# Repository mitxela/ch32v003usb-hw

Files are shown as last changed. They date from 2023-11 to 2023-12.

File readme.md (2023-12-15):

# CH32V003 USB dev board

This is a simple and tiny USB dev board for the CH32V003 using CNLohr's ch32v003fun and rv003usb.

photo of dev board

2 layer board, 0.8mm thickness.

The 1.5K resistor can be connected either to D5 or to VDD (not both). The series resistors on the underside are optional, cut the traces under them if you want to fit them.

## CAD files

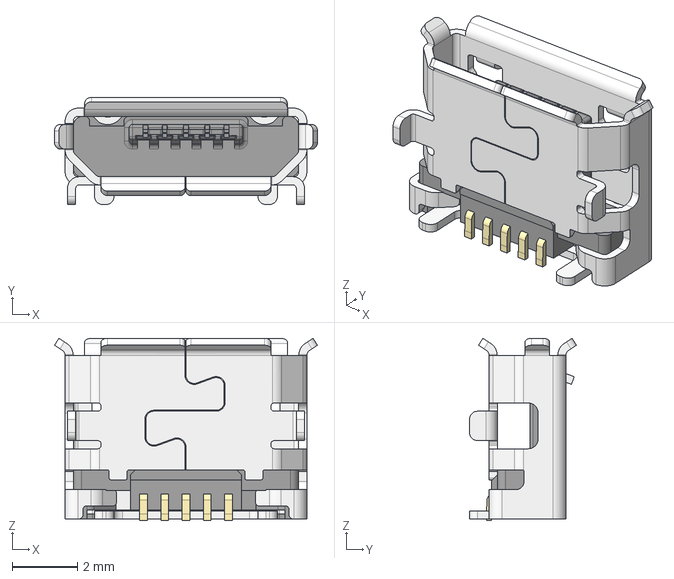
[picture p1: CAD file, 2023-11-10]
10118194-colour.stp
8.05 x 3.27 x 5.58 mm

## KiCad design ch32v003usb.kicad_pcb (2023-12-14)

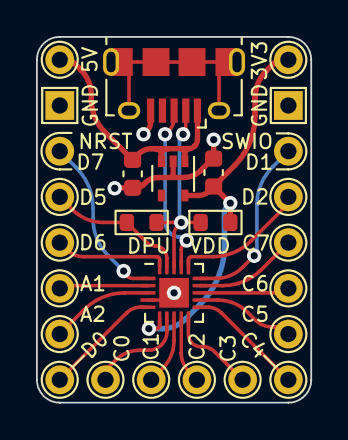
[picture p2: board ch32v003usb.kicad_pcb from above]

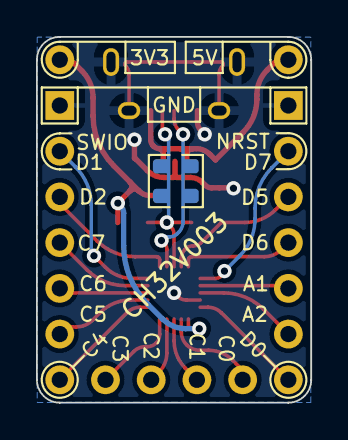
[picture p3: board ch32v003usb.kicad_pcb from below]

Board: 2 copper layers, 15.2 x 20.3 mm, 29 parts (2 on the bottom side), 21 nets.

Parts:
C1, C2: 1u; C_0603_1608Metric
J1: USB_B_Micro; USB_Micro-B_Amphenol_10118194_Horizontal
R1, R2: 1K5; R_0603_1608Metric
R3, R4: 33R; R_0603_1608Metric
TP1: C5; TestPoint_THTPad_D1.5mm_Drill0.7mm
TP2: D6; TestPoint_THTPad_D1.5mm_Drill0.7mm
TP3: A2; TestPoint_THTPad_D1.5mm_Drill0.7mm
TP4: D0; TestPoint_THTPad_D1.5mm_Drill0.7mm
TP5: C1; TestPoint_THTPad_D1.5mm_Drill0.7mm
TP6: 3V3; TestPoint_THTPad_D1.5mm_Drill0.7mm
TP7: C2; TestPoint_THTPad_D1.5mm_Drill0.7mm
TP8: C0; TestPoint_THTPad_D1.5mm_Drill0.7mm
TP9: C3; TestPoint_THTPad_D1.5mm_Drill0.7mm
TP10: C4; TestPoint_THTPad_D1.5mm_Drill0.7mm
TP11: C6; TestPoint_THTPad_D1.5mm_Drill0.7mm
TP12: D7; TestPoint_THTPad_D1.5mm_Drill0.7mm
TP13: C7; TestPoint_THTPad_D1.5mm_Drill0.7mm
TP14: A1; TestPoint_THTPad_D1.5mm_Drill0.7mm
TP15: D1; TestPoint_THTPad_D1.5mm_Drill0.7mm
TP16, TP20: GND; TestPoint_THTPad_1.5x1.5mm_Drill0.7mm
TP17: D2; TestPoint_THTPad_D1.5mm_Drill0.7mm
TP18: 5V; TestPoint_THTPad_D1.5mm_Drill0.7mm
TP19: D5; TestPoint_THTPad_D1.5mm_Drill0.7mm
U1: CH32V003F4U6; QFN-20-1EP_3x3mm_P0.4mm_EP1.65x1.65mm
U2: MIC5365-3.3YC5; SOT-353_SC-70-5

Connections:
/DPU: R1.2, TP19.1, U1.19 (PD5)
/USB_D+: J1.3 (D+), R4.1, R4.2, U1.17 (PD3)
/USB_D-: J1.2 (D-), R1.1, R2.1, R3.1, R3.2, U1.18 (PD4)
GND: C1.2, C2.2, J1.5 (GND), J1.6 (Shield), TP16.1, TP20.1, U1.4 (VSS), U1.21 (PAD), U2.2 (GND)
unnamed: C2.1, J1.1 (VBUS), TP18.1, U2.1 (VIN), U2.3 (EN)
unnamed: TP14.1, U1.2 (PA1)
unnamed: TP3.1, U1.3 (PA2)
unnamed: TP8.1, U1.7 (PC0)
unnamed: TP5.1, U1.8 (PC1)
unnamed: TP7.1, U1.9 (PC2)
unnamed: TP9.1, U1.10 (PC3)
unnamed: TP10.1, U1.11 (PC4)
unnamed: TP1.1, U1.12 (PC5)
unnamed: TP11.1, U1.13 (PC6)
unnamed: TP13.1, U1.14 (PC7)
unnamed: TP4.1, U1.5 (PD0)
unnamed: TP15.1, U1.15 (PD1/SWIO)
unnamed: TP17.1, U1.16 (PD2)
unnamed: TP2.1, U1.20 (PD6)
unnamed: TP12.1, U1.1 (PD7)
VDD: C1.1, R2.2, TP6.1, U1.6 (VDD), U2.5 (VOUT)

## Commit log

2023-11-10 routing about done
    [ch32v003usb.kicad_pcb]
2023-11-10 ground plane
    [ch32v003usb.kicad_pcb]
2023-11-10 Silkscreen updates
    [ch32v003usb.kicad_pcb]
2023-12-14 Enlarge plated holes
    [ch32v003usb.kicad_pcb]
